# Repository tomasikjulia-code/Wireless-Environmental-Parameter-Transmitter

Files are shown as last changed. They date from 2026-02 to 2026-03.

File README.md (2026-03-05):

# Wireless Environmental Parameter Transmitter

A professional, compact IoT solution for high-precision environmental monitoring based on the **ESP32-C3** (RISC-V) architecture. This project integrates sensing, power management, and local visualization into a single PCB.

---

## Overview

This device is designed to measure, display, and transmit environmental data (Temperature & Humidity) over Wi-Fi or Bluetooth LE. It features a robust power circuit, making it suitable for battery-operated remote applications.

### Key Features
* **Microcontroller:** ESP32-C3 with 2.4GHz Wi-Fi and BLE 5.0.
* **High-Precision Sensing:** Integrated **SHT45** sensor for accurate climate data.
* **Display Support:** Dedicated I2C header for OLED displays (SSD1306/SH1106).
* **Power System:** USB-C connectivity for power and programming.
    * Li-ion/Li-Po battery charging via **NCP73831**.
    * Battery voltage sensing for level monitoring.
* **User Interface:** Physical buttons for `Reset` and `Boot`.

---

## Hardware Specifications

The schematic was developed using **KiCad 9.0**. Key circuit blocks include:

* **RF Section:** Optimized antenna matching network for the 2.4GHz band.
* **Power Rail:** Stable 3.3V LDO regulator with decoupling capacitors for noise reduction.
* **Protection:** ESD protection on the USB-C data lines (D+/D-).
* **Flash Memory:** External SPI Flash for extended data logging or complex firmware.

<p align="center">
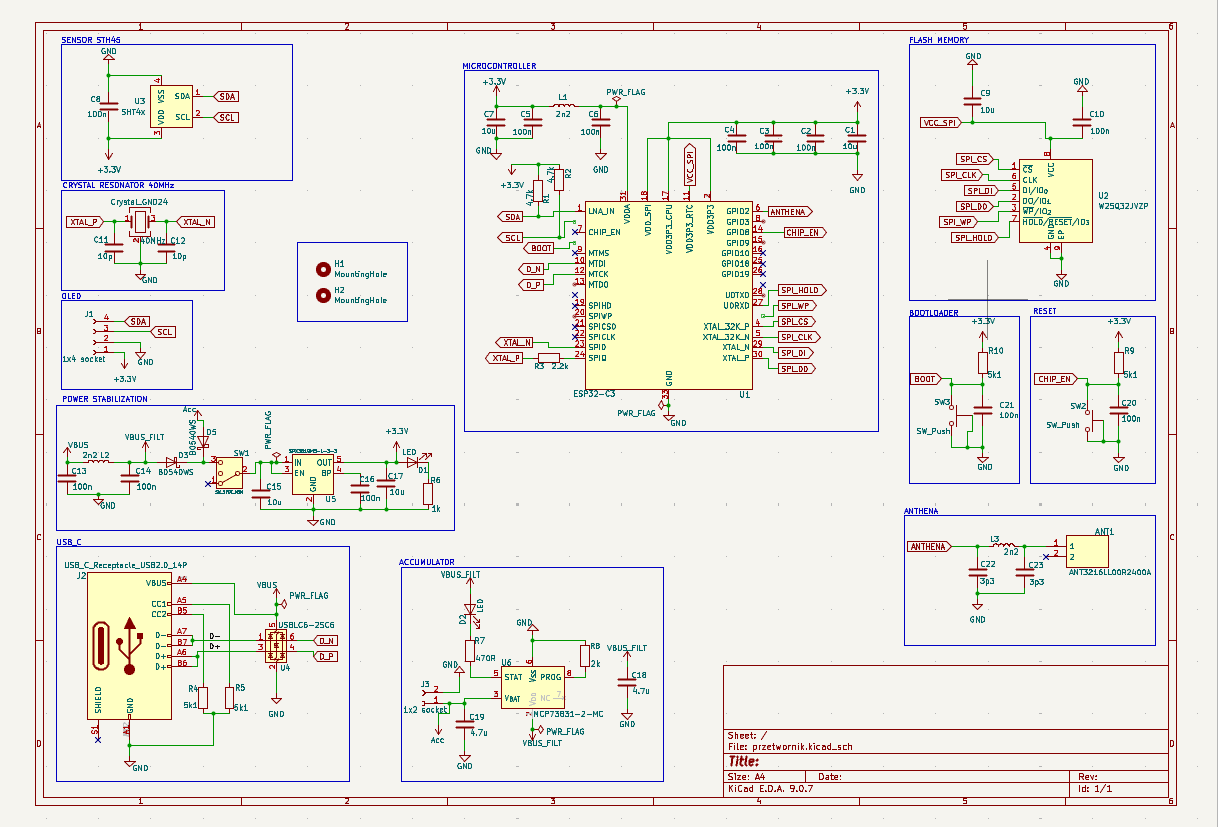
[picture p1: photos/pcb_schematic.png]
Render projektu płytki
  
</p>

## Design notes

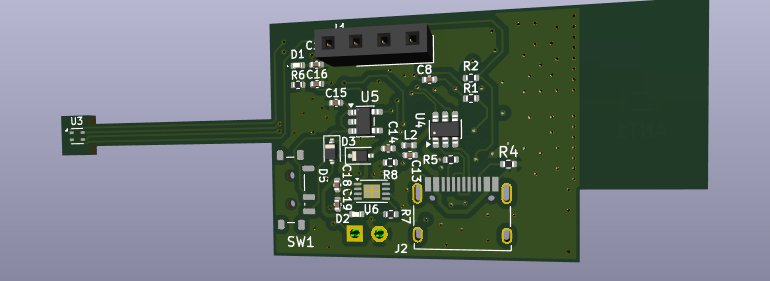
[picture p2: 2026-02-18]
photos/3D view back.png

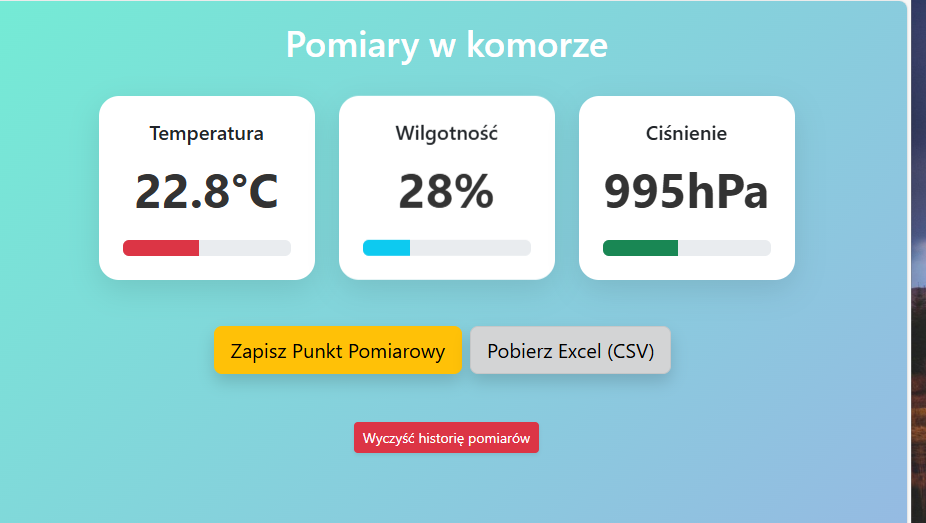
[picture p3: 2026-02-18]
photos/website.png

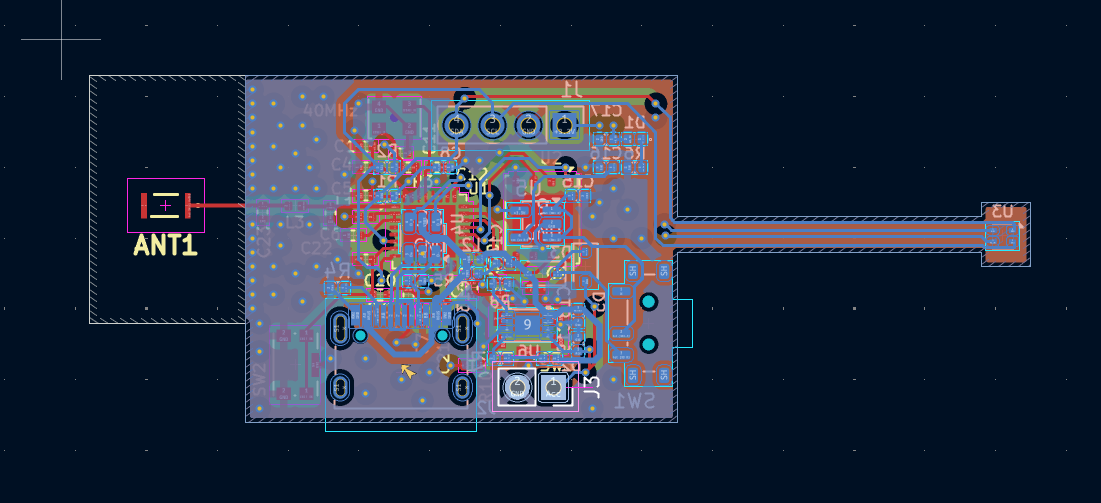
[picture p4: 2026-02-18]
photos/PCB back.png

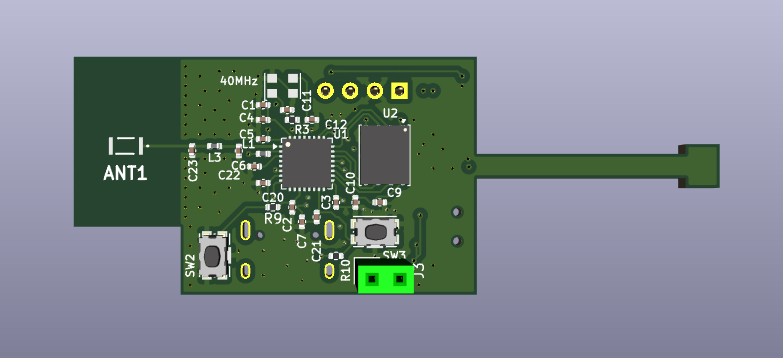
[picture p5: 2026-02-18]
photos/3D view front.png

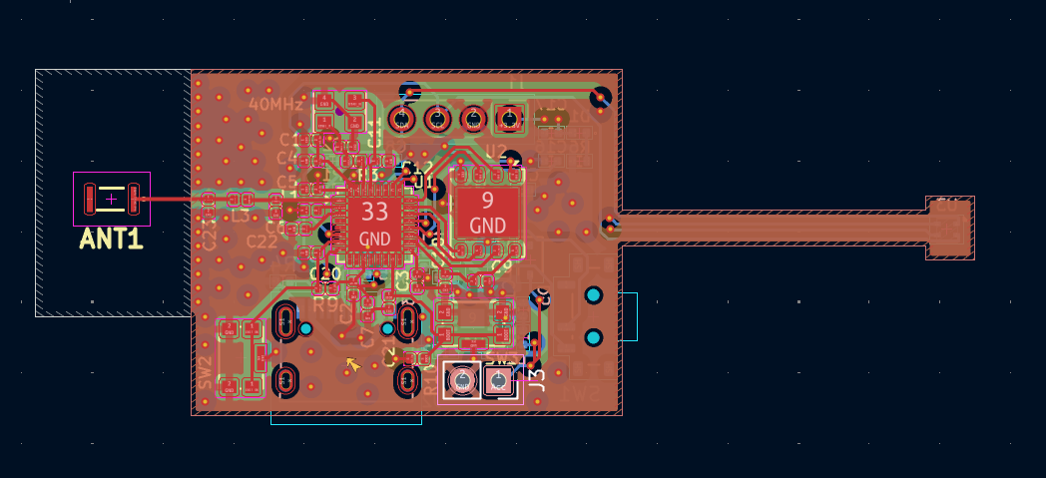
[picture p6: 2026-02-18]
photos/PCB front.png

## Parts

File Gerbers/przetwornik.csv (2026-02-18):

Reference | Qty | Value | DNP | Exclude from BOM | Exclude from Board | Footprint | Datasheet | LCSC
ANT1 | 1 | ANT3216LL00R2400A |  |  |  | KiCad:ANT3216LL00R2400A | https://eu.mouser.com/datasheet/2/336/datasheet_ant3216ll00r2400a_v1_1617827483-2529684.pdf | C293767
C1,C7,C9,C15,C17 | 5 | 10u |  |  |  | Capacitor_SMD:C_0402_1005Metric | ~ | C15525
C2,C3,C4,C5,C6,C8,C10,C13,C14,C16,C20,C21 | 12 | 100n |  |  |  | Capacitor_SMD:C_0402_1005Metric | ~ | C1525
C11,C12 | 2 | 10p |  |  |  | Capacitor_SMD:C_0402_1005Metric | ~ | C1545
C18,C19 | 2 | 4.7u |  |  |  | Capacitor_SMD:C_0402_1005Metric | ~ | C23687
C22,C23 | 2 | 3p3 |  |  |  | Capacitor_SMD:C_0402_1005Metric | ~ | C1565
Crystal_GND24 | 1 | 40MHz |  |  |  | Oscillator:Oscillator_SMD_EuroQuartz_XO32-4Pin_3.2x2.5mm | ~ | C9010
D1,D2 | 2 | LED |  |  |  | LED_SMD:LED_0402_1005Metric | ~ | C74338
D3,D5 | 2 | B0540WS |  |  |  | Diode_SMD:D_SOD-323 | ~ | C98664
H1,H2 | 2 | MountingHole |  | Wyklucz z BOM |  | MountingHole:MountingHole_2.7mm | ~
J1 | 1 | 1x4 socket |  | Wyklucz z BOM |  | Connector_PinSocket_2.54mm:PinSocket_1x04_P2.54mm_Vertical | ~
J2 | 1 | USB_C_Receptacle_USB2.0_14P |  |  |  | Connector_USB:USB_C_Receptacle_HRO_TYPE-C-31-M-12 | https://www.usb.org/sites/default/files/documents/usb_type-c.zip | C165948
J3 | 1 | 1x2 socket |  | Wyklucz z BOM |  | Connector_PinSocket_2.54mm:PinSocket_1x02_P2.54mm_Vertical | ~
L1,L2,L3 | 3 | 2n2 |  |  |  | Inductor_SMD:L_0402_1005Metric | ~ | C76790
R1,R2 | 2 | 4.7k |  |  |  | Resistor_SMD:R_0402_1005Metric | ~ | C174177
R3 | 1 | 22k |  |  |  | Resistor_SMD:R_0402_1005Metric | ~ | C25547
R4,R5,R9,R10 | 4 | 5k1 |  |  |  | Resistor_SMD:R_0402_1005Metric | ~ | C22356228,C22356228
R6 | 1 | 1k |  |  |  | Resistor_SMD:R_0402_1005Metric | ~ | C173697
R7 | 1 | 470R |  |  |  | Resistor_SMD:R_0402_1005Metric | ~ | C174152
R8 | 1 | 2k |  |  |  | Resistor_SMD:R_0402_1005Metric | ~ | C22369189
SW1 | 1 | SW_SPDT_MSM |  |  |  | Button_Switch_SMD:SW_SPDT_Shouhan_MSK12C02 | ~ | C2681566
SW2,SW3 | 2 | SW_Push |  |  |  | Button_Switch_SMD:SW_Push_1P1T-SH_NO_CK_KMR2xxG | ~ | C72443
U1 | 1 | ESP32-C3 |  |  |  | Package_DFN_QFN:QFN-32-1EP_5x5mm_P0.5mm_EP3.7x3.7mm | https://www.espressif.com/sites/default/files/documentation/esp32-c3_datasheet_en.pdf | C2838500
U2 | 1 | W25Q32JVZP |  |  |  | Package_SON:WSON-8-1EP_6x5mm_P1.27mm_EP3.4x4.3mm | http://www.winbond.com/resource-files/w25q32jv%20revg%2003272018%20plus.pdf | C571260
U3 | 1 | SHT4x |  |  |  | Sensor_Humidity:Sensirion_DFN-4_1.5x1.5mm_P0.8mm_SHT4x_NoCentralPad | https://sensirion.com/media/documents/33FD6951/624C4357/Datasheet_SHT4x.pdf | C5360602
U4 | 1 | USBLC6-2SC6 |  |  |  | Package_TO_SOT_SMD:SOT-23-6 | https://www.st.com/resource/en/datasheet/usblc6-2.pdf | C7519
U5 | 1 | SPX3819M5-L-3-3 |  |  |  | Package_TO_SOT_SMD:SOT-23-5 | https://www.exar.com/content/document.ashx?id=22106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 | C9055
U6 | 1 | MCP73831-2-MC |  |  |  | Package_DFN_QFN:DFN-8-1EP_3x2mm_P0.5mm_EP1.7x1.4mm | http://ww1.microchip.com/downloads/en/DeviceDoc/20001984g.pdf | C150772

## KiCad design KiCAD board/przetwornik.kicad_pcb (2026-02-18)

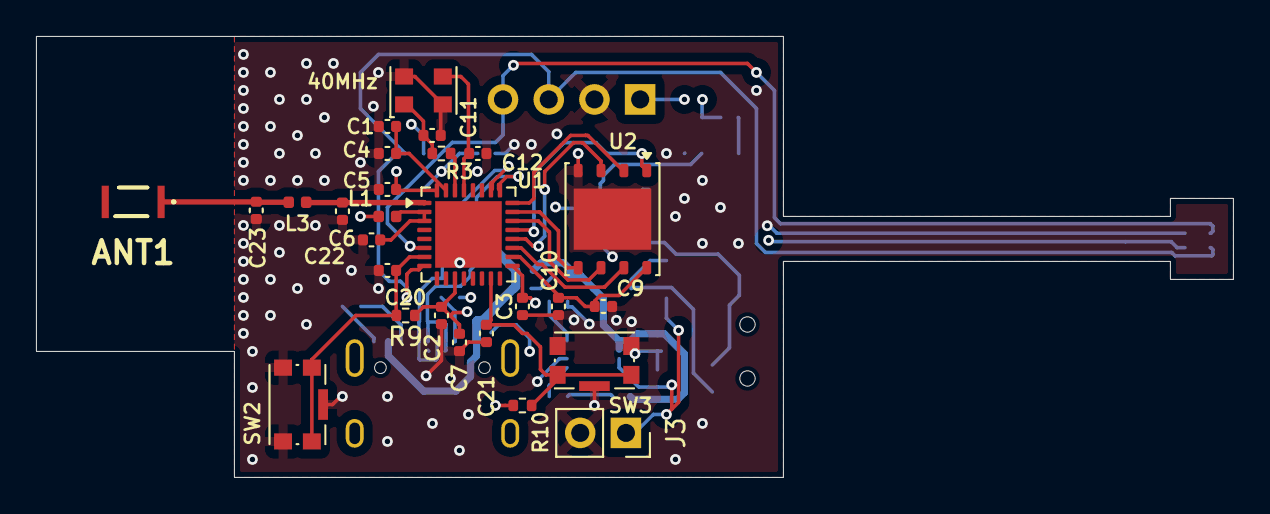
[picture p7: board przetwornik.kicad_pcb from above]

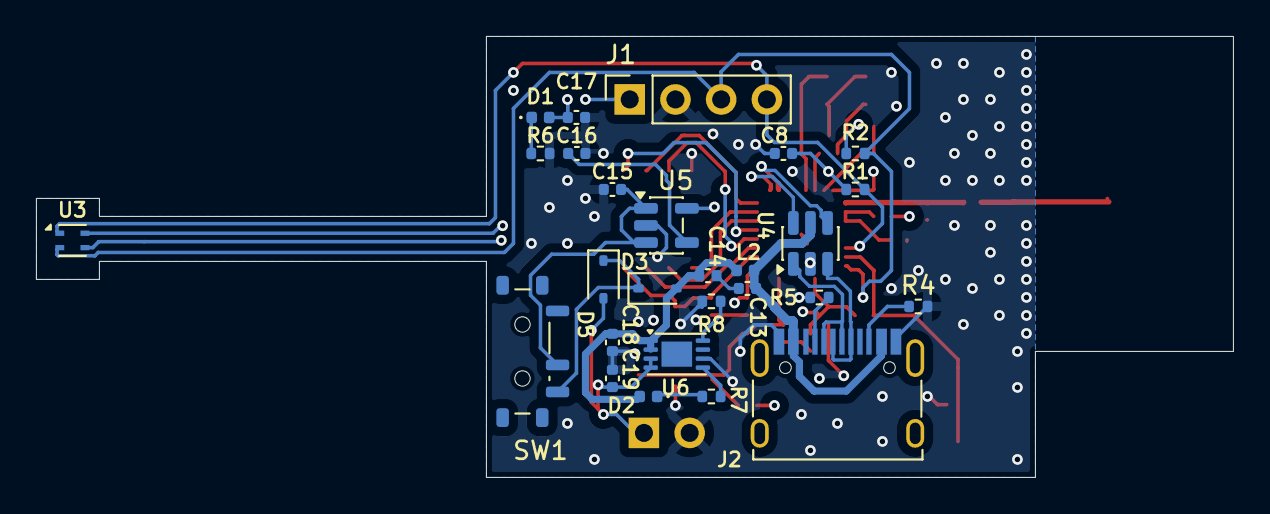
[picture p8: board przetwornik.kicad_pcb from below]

Board: 4 copper layers, 66.5 x 24.5 mm, 54 parts (27 on the bottom side), 36 nets.

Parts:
40MHz: 40MHz; Oscillator_SMD_EuroQuartz_XO32-4Pin_3.2x2.5mm
ANT1: ANT3216LL00R2400A
C1, C7, C9, C15, C17: 10u; C_0402_1005Metric
C2, C3, C4, C5, C6, C8, C10, C13, C14, C16, C20, C21: 100n; C_0402_1005Metric
C11, C12: 10p; C_0402_1005Metric
C18, C19: 4.7u; C_0402_1005Metric
C22, C23: 3p3; C_0402_1005Metric
D1, D2: LED; LED_0402_1005Metric
D3, D5: B0540WS; D_SOD-323
J1: 1x4 socket; PinSocket_1x04_P2.54mm_Vertical
J2: USB_C_Receptacle_USB2.0_14P; USB_C_Receptacle_HRO_TYPE-C-31-M-12
J3: 1x2 socket; PinSocket_1x02_P2.54mm_Vertical
L1, L2, L3: 2n2; L_0402_1005Metric
R1, R2: 4.7k; R_0402_1005Metric
R3: 22k; R_0402_1005Metric
R4, R5, R9, R10: 5k1; R_0402_1005Metric
R6: 1k; R_0402_1005Metric
R7: 470R; R_0402_1005Metric
R8: 2k; R_0402_1005Metric
SW1: SW_SPDT_MSM; SW_SPDT_Shouhan_MSK12C02
SW2, SW3: SW_Push; SW_Push_1P1T-SH_NO_CK_KMR2xxG
U1: ESP32-C3; QFN-32-1EP_5x5mm_P0.5mm_EP3.7x3.7mm
U2: W25Q32JVZP; WSON-8-1EP_6x5mm_P1.27mm_EP3.4x4.3mm
U3: SHT4x; Sensirion_DFN-4_1.5x1.5mm_P0.8mm_SHT4x_NoCentralPad
U4: USBLC6-2SC6; SOT-23-6
U5: SPX3819M5-L-3-3; SOT-23-5
U6: MCP73831-2-MC; DFN-8-1EP_3x2mm_P0.5mm_EP1.7x1.4mm

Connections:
+3.3V: C1.2, C2.2, C3.2, C4.2, C5.2, C7.2, C8.2, C17.1, D1.2 (A), J1.1, L1.1, R1.1, R2.1, R9.1, R10.1, U1.11 (VDD3P3_RTC), U1.17 (VDD3P3_CPU), U1.31 (VDDA), U1.32 (VDDA), U3.3 (VDD), U5.5 (OUT)
/D+: J2.A6 (D+), J2.B6 (D+), U4.3 (I/O2)
/D-: J2.A7 (D-), J2.B7 (D-), U4.1 (I/O1)
ANTHENA: C22.1, L3.1, U1.1 (LNA_IN)
Acc: C19.1, D5.2 (A), J3.1, U6.3 (V_{BAT}), U6.4 (V_{BAT})
BOOT: C21.1, R10.2, SW3.1, U1.15 (GPIO9)
CHIP_EN: C20.1, R9.2, SW2.1, U1.7 (CHIP_EN)
D_N: U1.25 (GPIO18), U4.6 (I/O1)
D_P: U1.26 (GPIO19), U4.4 (I/O2)
GND: 40MHz.2 (G), 40MHz.4 (G), C1.1, C2.1, C3.1, C4.1, C5.1, C6.1, C7.1, C8.1, C9.1, C10.1, C11.2, C12.2, C15.2, C16.2, C17.2, C18.2, C19.2, C20.2, C21.2, C22.2, C23.2, J1.2, J2.A1 (GND), J2.A12 (GND), J2.B1 (GND), J2.B12 (GND), J3.2, R4.2, R5.2, R6.2, R8.1, SW2.2, SW2.SH, SW3.2, SW3.SH, U1.33 (GND), U2.4 (GND), U2.9 (EP), U3.4 (VSS), U4.2 (GND), U5.2 (GND), U6.6 (V_{SS})
unnamed: ANT1.1, C23.1, L3.2
unnamed: C6.2, L1.2, U1.2 (VDD3P3), U1.3 (VDD3P3)
unnamed: C13.2, C14.2
unnamed: D1.1 (K), R6.1
unnamed: D2.1 (K), R7.1
unnamed: D3.1 (K), D5.1 (K), SW1.3 (4)
unnamed: J2.A5 (CC1), R5.1
unnamed: J2.B5 (CC2), R4.1
unnamed: C15.1, SW1.2 (3), U5.1 (IN), U5.3 (EN)
unnamed: R3.2, U1.30 (XTAL_P)
unnamed: C16.1, U5.4 (BP)
unnamed: R8.2, U6.8 (PROG)
unnamed: R7.2, U6.5 (STAT)
SCL: J1.3, R2.2, U1.8 (GPIO3), U3.2 (SCL)
SDA: J1.4, R1.2, U1.6 (GPIO2), U3.1 (SDA)
SPI_CLK: U1.22 (SPICLK), U2.6 (CLK)
SPI_CS: U1.21 (SPICS0), U2.1 (~CS)
SPI_D0: U1.24 (SPIQ), U2.2 (DO/IO_{1})
SPI_DI: U1.23 (SPID), U2.5 (DI/IO_{0})
SPI_HOLD: U1.19 (SPIHD), U2.7 (~HOLD/~RESET/IO_{3})
SPI_WP: U1.20 (SPIWP), U2.3 (~WP/IO_{2})
VBUS: C13.1, J2.A4 (VBUS), J2.A9 (VBUS), J2.B4 (VBUS), J2.B9 (VBUS), L2.1, U4.5 (VBUS)
VBUS_FILT: C14.1, C18.1, D2.2 (A), D3.2 (A), L2.2, U6.1 (V_{DD}), U6.2 (V_{DD})
VCC_SPI: C9.2, C10.2, U1.18 (VDD_SPI), U2.8 (VCC)
XTAL_N: 40MHz.3, C12.1, U1.29 (XTAL_N)
XTAL_P: 40MHz.1, C11.1, R3.1

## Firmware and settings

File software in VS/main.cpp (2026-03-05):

#include <Arduino.h>
#include <WiFi.h>
#include <WebServer.h>
#include <Wire.h>
#include <SensirionI2cSht4x.h> 
#include <Adafruit_GFX.h>
#include <Adafruit_SH110X.h>
#include "LittleFS.h"
#include "time.h"
#include <Preferences.h>

// Definicje pinów dla Beetle ESP32-C3 / DevKit
#define I2C_SDA 2 
#define I2C_SCL 3 
#define SCREEN_WIDTH 128
#define SCREEN_HEIGHT 64
#define OLED_RESET -1

// Globalne zmienne
const char* ssid = "";
const char* password = "";

float temp, hum;
float calTemp;
float p1r, p1v, p2r, p2v, p3r, p3v;

Preferences prefs;
Adafruit_SH1106G display(SCREEN_WIDTH, SCREEN_HEIGHT, &Wire, OLED_RESET);
SensirionI2cSht4x sht4x; 
WebServer server(80);

/*
 * @brief Updates the OLED display with current environmental data.
 */
void updateDisplay() {
  display.clearDisplay();
  display.setCursor(0,0);
  display.setTextSize(1);
  display.printf("T: %.2f%cC", calTemp, (char)247);
  display.setCursor(0, 20);
  display.printf("W: %.2f %%RH", hum);
  display.display();
}
/*
 * @brief Calibrates temperature using polynomial interpolation with Lagrange method
 * @param raw - raw value 
 * @param p1r, p2r, p3r - raw readings that were apply in a reference points
 * @param p1v, p2v, p3v - reference values that were apply in a reference points
 * @return The calibrated temperature as a float. Returns the original raw value if points are too close to each other to avoid division by zero.
*/
float getCalibrated(float raw) {

  if (abs(p1r - p2r) < 0.001 || abs(p1r - p3r) < 0.001 || abs(p2r - p3r) < 0.001) {
    return raw;
  }

  float L1 = p1v * ((raw - p2r) * (raw - p3r)) / ((p1r - p2r) * (p1r - p3r));
  float L2 = p2v * ((raw - p1r) * (raw - p3r)) / ((p2r - p1r) * (p2r - p3r));
  float L3 = p3v * ((raw - p1r) * (raw - p2r)) / ((p3r - p1r) * (p3r - p2r));

  return L1 + L2 + L3;
}

/*
 * @brief Calculates relative humidity corrected for temperature difference.
 * Uses saturation vapor pressure (Magnus formula) to adjust humidity 
 * from the sensor's raw temperature to the calibrated temperature.
 * @param rawTemp - Temperature measured by the BME280 sensor.
 * @param rawHum - Humidity measured by the BME280 sensor.
 * @param calTemp - Calibrated temperature value.
 * @return Corrected relative humidity in % (clamped to 0-100 range).
 */
float getCorrectedHumidity(float rawTemp, float rawHum, float calTemp) {

  auto getSaturationPressure = [](float t) {return 6.112 * exp((17.67 * t) / (t + 243.5));};

  float es_raw = getSaturationPressure(rawTemp);
  float es_cal = getSaturationPressure(calTemp);

  float e = (rawHum / 100.0) * es_raw;

  float correctedHum = (e / es_cal) * 100.0;

  if (correctedHum > 100.0) return 100.0;
  if (correctedHum < 0.0) return 0.0;
  
  return correctedHum;
}
/*
 * @brief Remembers calibration points even if the power will be off.  
 * @param p1r, p2r, p3r - raw readings that were apply in a reference points
 * @param p1v, p2v, p3v - reference values that were apply in a reference points
*/
void loadCalibration() {
    prefs.begin("calib", true);
    p1r = prefs.getFloat("p1r", 10.0); p1v = prefs.getFloat("p1v", 10.0);
    p2r = prefs.getFloat("p2r", 40.0); p2v = prefs.getFloat("p2v", 40.0);
    p3r = prefs.getFloat("p3r", 80.0); p3v = prefs.getFloat("p3v", 80.0);
    prefs.end();
}

void UpdateData() {
    float rawTemp = 0;
    float rawHum = 0;
    // Sensirion API: odczyt wysokiej precyzji
    uint16_t error = sht4x.measureHighPrecision(rawTemp, rawHum);
    if (!error) {
        temp = rawTemp;
        calTemp = getCalibrated(temp);
        hum = getCorrectedHumidity(temp, rawHum, calTemp);
    }
}

/*--------Web function--------
 * This function provides the functionallity of website. It creates three blocks, each for different parametr with the diagram. It also creates a buttons:
   1) for saving current data,
   2) for downloading all saved data
   3) for earasing all previous data 
 * There is also a java script which enables refreshing only sensor parameters every 5 seconds on the website.
 */
void handleroot(){

String html = "<!DOCTYPE html><html lang='pl'>";

//Title
html += "<head>";
html += "<meta charset='UTF-8'><meta name='viewport' content='width=device-width, initial-scale=1'>";
html += "<title>Panel ESP32</title>";
html += "<link href='https://cdn.jsdelivr.net/npm/bootstrap@5.3.0/dist/css/bootstrap.min.css' rel='stylesheet'>";

//Java script
html += "<script>";
html += "setInterval(function() {";
html += " fetch('/readData').then(response => response.json()).then(data => {";
html += " let diff = data.calTemp - data.temp;";
html += " let diffText = (diff >= 0 ? '+' : '') + diff.toFixed(2);";
html += " document.getElementById('temp_val').innerHTML = data.calTemp.toFixed(2);";
html += " document.getElementById('temp_diff').innerHTML = '(' + diffText + ' °C)';";
html += " document.getElementById('hum_val').innerHTML = data.hum.toFixed(2);";
html += " document.getElementById('pressure_val').innerHTML = data.pressure.toFixed(2);";
html += " document.getElementById('temp_bar').style.width = (data.calTemp / 50 * 100) + '%';";
html += " document.getElementById('hum_bar').style.width = data.hum + '%';";
html += " document.getElementById('pressure_bar').style.width = ((data.pressure - 950) / 100 * 100) + '%';"; 
html += " });";
html += "}, 5000);"; 

//Calibration
html += "function saveCalibration() {";
  html += "  const form = document.getElementById('calibForm');";
  html += "  const formData = new FormData(form);";
  html += "  const params = new URLSearchParams(formData);";
  html += "  fetch('/saveCalib?' + params.toString())";
  html += "    .then(response => response.text())";
  html += "    .then(msg => {";
  html += "      alert(msg);";
  html += "      window.location.reload();";
  html += "    });";
  html += "}";
//Functionality of button Save data
html += "function saveData() {";
html += "  fetch('/save').then(response => response.text()).then(msg => alert(msg));";
html += "}";

//Functionality of button Clear all data
html += "function clr() {";
html += "  if(confirm('Czy na pewno chcesz BEZPOWROTNIE usunąć wszystkie zapisane pomiary?')) {";
html += "    fetch('/clear').then(response => response.text()).then(msg => {";
html += "      alert(msg);";
html += "      window.location.reload();"; 
html += "    });";
html += "  }";
html += "}";
html += "</script>";

//Visual aspects of website
html += "<style>";
html += "body { background: linear-gradient(135deg, #74ebd5 0%, #9face6 100%); min-height: 100vh; padding: 20px; }";
html += ".card { border: none; border-radius: 20px; box-shadow: 0 10px 30px rgba(0,0,0,0.1); transition: 0.3s; }";
html += ".card:hover { transform: translateY(-5px); }";
html += ".value { font-size: 3rem; font-weight: bold; color: #333; }";
html += ".btn-group-custom { margin-top: 30px; text-align: center; }";
html += ".calib-box { margin-top: 80px; padding: 20px; background: rgba(255,255,255,0.2); border-radius: 15px; border: 1px solid white; }";
html += "</style></head>";

html += "<body><div class='container'><div class='row justify-content-center'>";
html += "<div class='col-12 text-center mb-4 text-white'><h1>Pomiary w komorze</h1></div>";

//Cards for every parameter
html += "<div class='col-md-4 mb-3'><div class='card p-4 text-center'><h5>Temperatura</h5><div class='value'><span id='temp_val'>--</span>&deg;C</div><div id='temp_diff' style='font-size: 1.2rem; color: #666;'>--</div><div class='progress mt-3'><div id='temp_bar' class='progress-bar bg-danger' style='width: 0%'></div></div></div></div>";
html += "<div class='col-md-4 mb-3'><div class='card p-4 text-center'><h5>Wilgotność</h5><div class='value'><span id='hum_val'>--</span>%</div><div class='progress mt-3'><div id='hum_bar' class='progress-bar bg-info' style='width: 0%'></div></div></div></div>";

//Buttons
html += "<div class='col-12 btn-group-custom'>";
html += "<button onclick='saveData()' class='btn btn-light btn-lg me-2 shadow'>Zapisz Punkt Pomiarowy</button>";
html += "<a href='/download' class='btn btn-outline-success btn-lg me-2 shadow'>Pobierz Excel (CSV)</a>";
html += "<button onclick='clr()' class='btn btn-danger btn-sm shadow-sm d-block mx-auto mt-5'>Wyczyść historię pomiarów</button>";
html += "</div>";

//Calibration block
html += "<div class='calib-box mb-4'><h3>Ustawienia kalibracji 3-punktowej dla temperatury</h3><form id='calibForm' class='row g-3'>";
html += "<div class='col-md-4'><h6>Punkt Niski</h6>Odczyt: <input name='p1r' class='form-control' value='"+String(p1r)+"'> Wzorzec: <input name='p1v' class='form-control' value='"+String(p1v)+"'></div>";
html += "<div class='col-md-4'><h6>Punkt Średni</h6>Odczyt: <input name='p2r' class='form-control' value='"+String(p2r)+"'> Wzorzec: <input name='p2v' class='form-control' value='"+String(p2v)+"'></div>";
html += "<div class='col-md-4'><h6>Punkt Wysoki</h6>Odczyt: <input name='p3r' class='form-control' value='"+String(p3r)+"'> Wzorzec: <input name='p3v' class='form-control' value='"+String(p3v)+"'></div>";
html += "<div class='col-12 mt-3'><button type='button' onclick='saveCalibration()' class='btn btn-success w-100'>Zastosuj i Zapisz Kalibrację</button></div>";
html += "</form></div>";

html += "</div></div></body></html>";

//Sending all date to website
server.send(200, "text/html", html);
}

/*
 * @brief Sends current sensor readings in JSON format.
 * Used by the web interface's JavaScript to update the dashboard 
 * without reloading the entire page.
 */
void handledata() {
    UpdateData();
    String json = "{\"temp\":" + String(temp, 2) + ",\"calTemp\":" + String(calTemp, 2) + ",\"hum\":" + String(hum, 2) + "}";
    server.send(200, "application/json", json);
}
/*----------Function for Creating File------------
 * This function is resposible for saving data to a file named pomiary.csv. 
 * When this file doesn't exist it creates it with headers for easy identification.
 * This function also provides real time aspect, so the measurements are identify with the time.
*/
void handleSave() {

  bool fileExists = LittleFS.exists("/pomiary.csv");

  File file = LittleFS.open("/pomiary.csv", FILE_APPEND);

  if(!file) {server.send(500, "text/plain", "Blad zapisu pliku");return;}
  if(!fileExists || file.size() == 0) {file.println("Data i Godzina,Temperatura [C],Wilgotnosc [%],Cisnienie [hPa]");}

  struct tm timeinfo;
  char timeStringBuff[20] = "Brak czasu";

  if(getLocalTime(&timeinfo)) {strftime(timeStringBuff, sizeof(timeStringBuff), "%Y-%m-%d %H:%M:%S", &timeinfo);}

  file.printf("%s,%.2f,%.2f\n", timeStringBuff, temp, hum);
  file.close();
  server.send(200, "text/plain", "Zapisano pomiar!");
}

/*---------Setup Function--------
 * This function is run only one time at the beggining. It sets all important data like: time, baundrate and pins
 * It starts littleFS, bme and display
 * It sends information for the website
 * At the end it launch server
*/

void setup() {
    Serial.begin(115200);
    Wire.begin(I2C_SDA, I2C_SCL);
    loadCalibration();

    if(!LittleFS.begin(true)) Serial.println("LittleFS Error");
    
    // Inicjalizacja Sensirion SHT4x z adresem 0x44
    sht4x.begin(Wire, 0x44); 
    sht4x.softReset();
    delay(10);

    if(!display.begin(0x3C, true)) Serial.println("OLED Error");
    display.clearDisplay();
    display.setTextColor(SH110X_WHITE);
    display.println("SHT45 Ready...");
    display.display();

    WiFi.begin(ssid, password);
    configTime(3600, 3600, "pool.ntp.org");
    while (WiFi.status() != WL_CONNECTED) {
    delay(500);
    Serial.print(".");
}
Serial.println("");
Serial.println("Połączono z WiFi!");
Serial.print("Adres IP: ");
Serial.println(WiFi.localIP());

server.on("/", handleroot);
  server.on("/readData", handledata);
  server.on("/save", handleSave);
  server.on("/saveCalib", []() {
    prefs.begin("calib", false);
    if(server.hasArg("p1r")) prefs.putFloat("p1r", server.arg("p1r").toFloat());
    if(server.hasArg("p1v")) prefs.putFloat("p1v", server.arg("p1v").toFloat());
    if(server.hasArg("p2r")) prefs.putFloat("p2r", server.arg("p2r").toFloat());
    if(server.hasArg("p2v")) prefs.putFloat("p2v", server.arg("p2v").toFloat());
    if(server.hasArg("p3r")) prefs.putFloat("p3r", server.arg("p3r").toFloat());
    if(server.hasArg("p3v")) prefs.putFloat("p3v", server.arg("p3v").toFloat());
    prefs.end();
    loadCalibration(); 
    server.send(200, "text/plain", "Kalibracja zapisana pomyślnie!");
  });
  server.on("/download", []() {
    if (!LittleFS.exists("/pomiary.csv")) {
        server.send(404, "text/plain", "Brak pliku. Zapisz najpierw jakis pomiar.");
        return;
    }
    File f = LittleFS.open("/pomiary.csv", FILE_READ);
    server.sendHeader("Cache-Control", "no-cache, no-store, must-revalidate");
    server.sendHeader("Pragma", "no-cache");
    server.sendHeader("Expires", "0");
    server.sendHeader("Content-Disposition", "attachment; filename=pomiary.csv");
    server.streamFile(f, "text/csv");
    f.close();
  });
  server.on("/clear", []() {
    LittleFS.remove("/pomiary.csv");
    File f = LittleFS.open("/pomiary.csv", FILE_WRITE);
    if(f) {
        f.println("Data i Godzina,Temperatura [C],Wilgotnosc [%],Cisnienie [hPa]");
        f.close();
        server.send(200, "text/plain", "Historia wyczyszczona. Nowy plik gotowy.");
    } else {
        server.send(500, "text/plain", "Blad tworzenia nowego pliku.");
    }
  });
  server.begin();
}
/*
 * @brief Updates display and data every two seconds 
 * @brief Saves data every one minute
 */
void loop(){
  server.handleClient();
  
  static unsigned long lastSensorUpdate = 0;
  static unsigned long lastDisplayUpdate = 0;
  static unsigned long lastAutoSave = 0;
  unsigned long currentMillis = millis();

  if (currentMillis - lastSensorUpdate > 2000) {
    UpdateData();
    lastSensorUpdate = currentMillis;
  }
  if (currentMillis - lastDisplayUpdate > 2000) {
    updateDisplay();
    lastDisplayUpdate = currentMillis;
  }
  if (currentMillis - lastAutoSave > 60000) {
    UpdateData();
    handleSave();
    lastAutoSave = currentMillis;
  }

}

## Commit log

2026-02-18 KiCAD files
    [przetwornik.csv, przetwornik.kicad_pcb, przetwornik.kicad_sch]
2026-02-18 Gerber files
    [przetwornik-B_Cu.gbl, przetwornik-B_Mask.gbs, przetwornik-B_Paste.gbp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]
